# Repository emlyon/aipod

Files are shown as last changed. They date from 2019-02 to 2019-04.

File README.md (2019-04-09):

# AIpod 

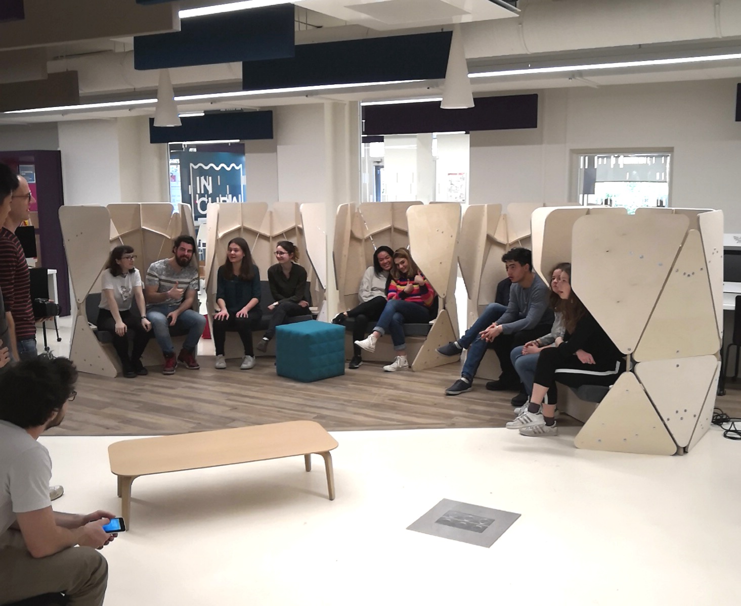
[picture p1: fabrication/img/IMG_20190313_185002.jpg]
  
AIpod is an open source chair that was designed and crafted at emlyon Business School’s makers’ lab during a bootcamp about Artificial Intelligence by staff, students and alumni.

IBM Watson NLU was used to analyze the topic, emotions and semantics of academic papers. Then, Google magenta AI composed piano musics based on this analysis. The LCD screen displays the author and title of the interpreted paper.

Seating in the chair, you can listen the sound of research, and discover research papers in a new way!

___

## Fabrication

### CNC milling

AIpod has been designed to be fabricated using a CNC router with plywood 18mm.

Use a 8mm flat milling bit to cut. The [3D model](fabrication/AIpod_chair.3dm) includes the layout for CNC milling 1250x2500mm plywood panels.

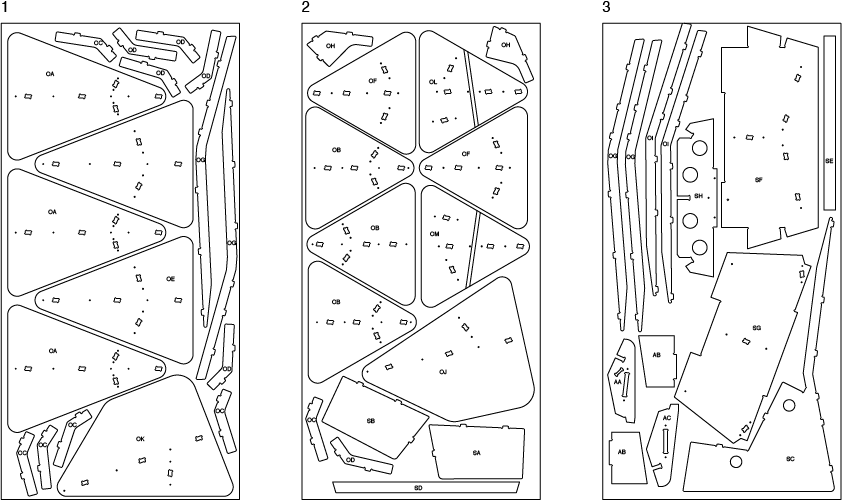
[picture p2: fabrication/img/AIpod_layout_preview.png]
AIpod_layout_preview


We used [Autodesk Fusion 360](https://www.autodesk.com/products/fusion-360/overview) to generate the toolpaths : you can find tutorials about the _Manufacture_ feature of Fusion 360 on [Autodesk website](https://f360ap.autodesk.com/courses#creating-toolpaths-and-programs-cam).

---

### Assembly

General assembly instructions can be found here : https://hackmd.io/7cDdYA7nRJGSax_ZulLNjg?both

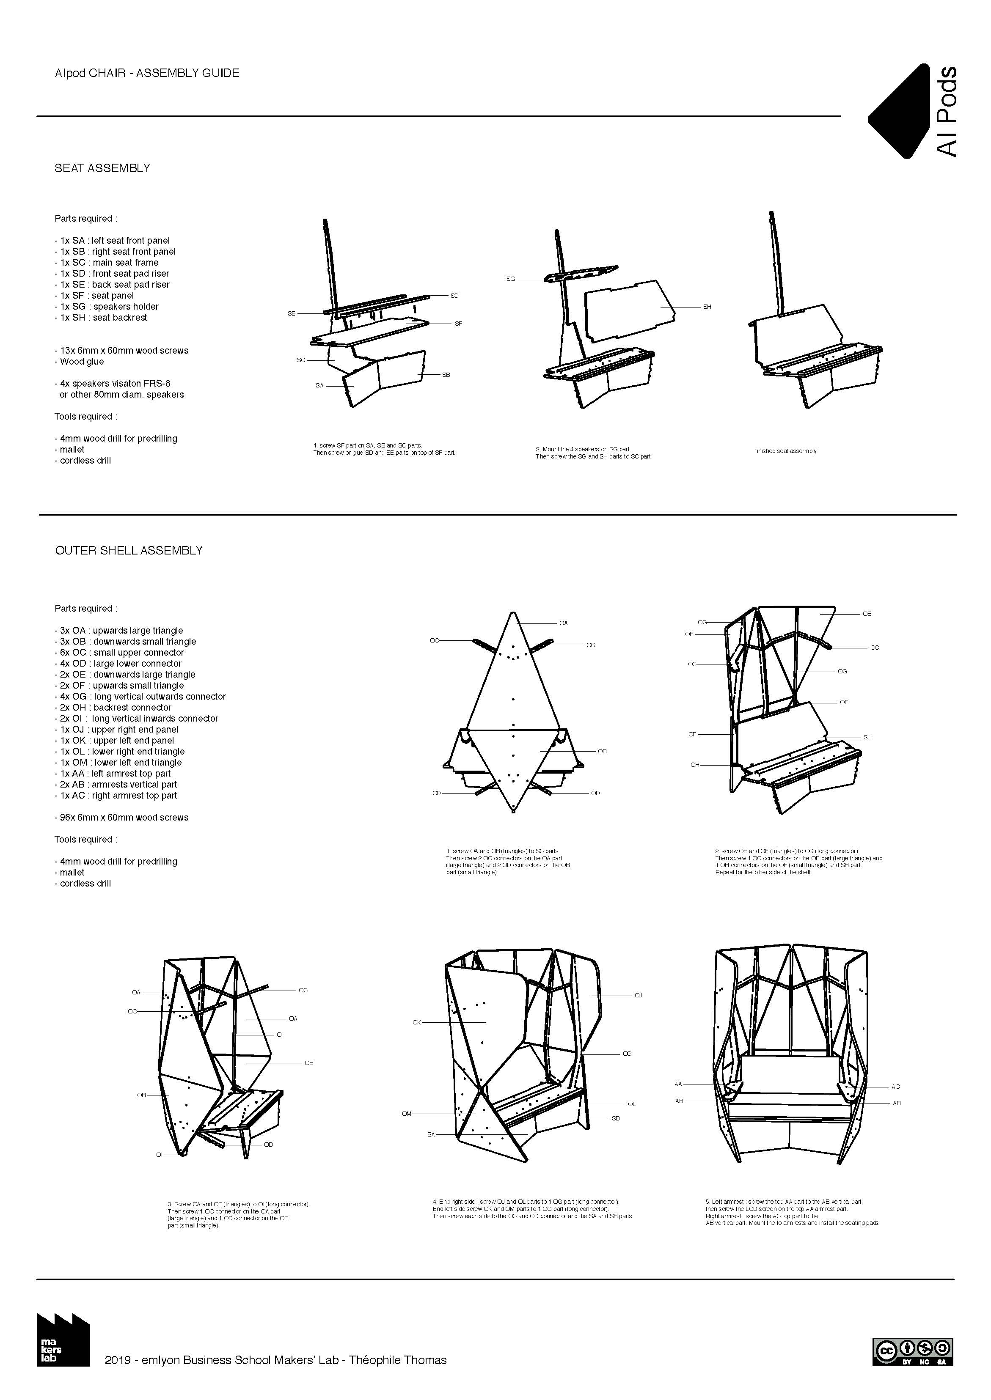
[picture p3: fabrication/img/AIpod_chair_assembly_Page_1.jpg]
  
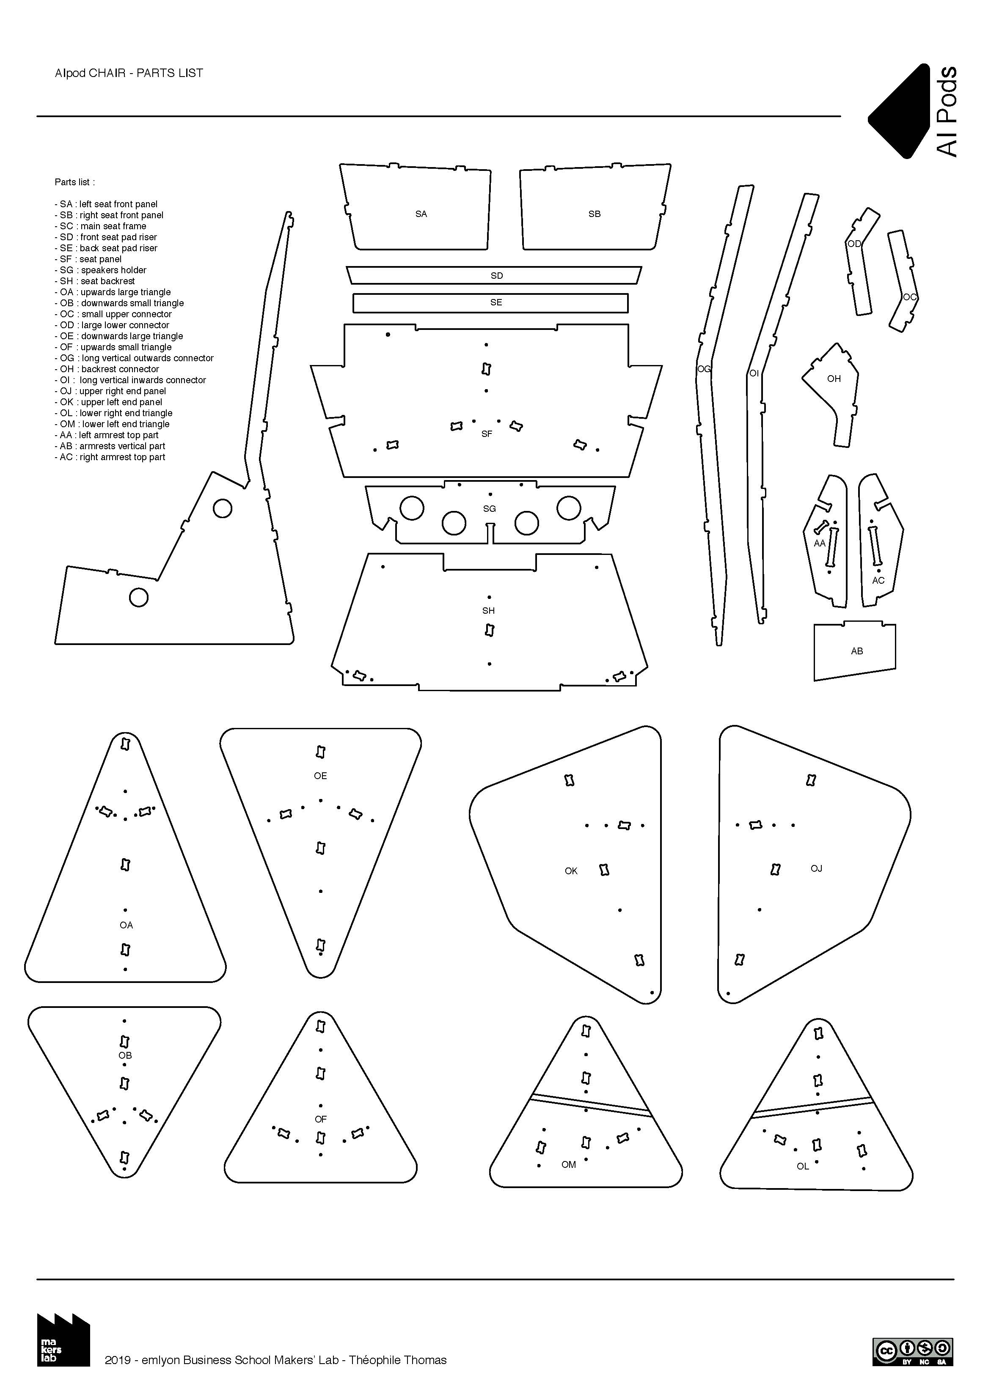
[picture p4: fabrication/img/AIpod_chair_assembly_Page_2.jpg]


A detailled list of the parts and an assembly guide can be found [in this pdf](fabrication/AIpod_chair_assembly.pdf).

___

## Electronic

### Bill of Material
- [Raspberry Pi 3](https://www.raspberrypi.org/products/)
- [16x2 LCD Display LCM1602C V2.1](http://www.datasheetcafe.com/lcm1602c-datasheet-pdf/)
- [Arcade buttons](https://www.amazon.fr/gp/product/B01N5DVINY)
- [Ampli CALIBER CA752](http://webshop.caliber.nl/products/view/details/ca75-2.html)
- [Speakers FRS 8-8 Ohm](http://www.visaton.de/en/products/fullrange-systems/frs-8-8-ohm)

### Wiring
wiring

16x2 LCD Display is connected as follow:
- RS is connected to GPIO16
- EN is connected to GPIO12
- D4 is connected to GPIO25
- D5 is connected to GPIO24
- D6 is connected to GPIO23
- D7 is connected to GPIO18
- (+ 4xGND and 2x5V)

[Buttons](https://www.amazon.fr/gp/product/B01N5DVINY) are connected to GPIO4, configured as input pullup. (+ GND)

___

### Install & run

Download the image [here](https://mega.nz/#!J9cXBCLA!xZrNihUM6XFwxSyXiPqJTmqI85lqSSZrZGT_HBga6Kw) and burn it on an 8GB micro SD using [etcher](https://www.balena.io/etcher/) or start with a fresh install of [Raspbian Stretch with desktop and recommended software](https://www.raspberrypi.org/downloads/raspbian/)

**Clone repo**
```bash
cd /home/pi
git clone https://github.com/emlyon/aipod
```

**Install Dependencies**
```bash
sudo apt-get update -y
sudo apt-get upgrade -y
sudo apt-get install python3-pip
sudo pip3 install pygame adafruit-blinka adafruit-circuitpython-charlcd
```
From [Update Your Pi to the Latest Raspbian](https://learn.adafruit.com/drive-a-16x2-lcd-directly-with-a-raspberry-pi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)

**Run**
```bash
cd /home/pi/aipod
python3 aipod.py
```

___

### Auto-update and run on boot

**Configure WIFI**
```bash
sudo raspi-config

# Set Wifi settings:
-> 2. Network Options
-> N2 Wi-fi
SSID: makerslab
passphrase: makerslab
```

**Run task on boot**
```bash
crontab -e

# and add:
@reboot sleep 10 && cd /home/pi/aipod && echo `{ git pull && echo '{"result":"up to date"}' > /home/pi/git_status.json ; } || echo '{"result":"could not update"}' > /home/pi/git_status.json` && python3 aipod.py
```

Finally create a hotspot with your phone using `makerslab`
 for **SSID and password**, and reboot the Raspberry Pi. LCD dislay should print `up to date`
 if successful, `could not update`
 otherwise.

___

### Resources
- [Adafruit-Blinka](https://pypi.org/project/Adafruit-Blinka/)
- [Adafruit CIRCUITPYTHON_CHARLCD Library](https://circuitpython.readthedocs.io/projects/charlcd/en/latest/)
- [pygame.mixer.music](https://www.pygame.org/docs/ref/music.html)
- [Drive a 16x2 LCD with the Raspberry Pi Output Character](https://learn.adafruit.com/drive-a-16x2-lcd-directly-with-a-raspberry-pi?view=all)

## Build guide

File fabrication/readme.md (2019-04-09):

# AIpod Chair

AIpod cosy chair

AIpod is an open source chair that was designed and crafted at emlyon Business School’s makers’ lab during a bootcamp about Artificial Intelligence by staff, students and alumni.

IBM Watson NLU was used to analyze the topic, emotions and semantics of academic papers. Then, Google magenta AI composed piano musics based on this analysis. The LCD screen displays the author and title of the interpreted paper.

Seating in the chair you can listen the sound of research, and discover research papers in a new way!

More info here :[makerslab.em-lyon.com](http://makerslab.em-lyon.com/)

AIpod project is licensed under the [CC by-nc-sa 4.0](https://creativecommons.org/licenses/by-nc-sa/4.0/) creative commons license



---

## Building instructions

### Electronics

Instructions for the electronics part used to play the sounds can be found on [this github repository](https://github.com/emlyon/aipod/blob/master/README.md)

---

### CNC milling

AIpod has been designed to be fabricated using a CNC router with plywood 18mm.

Use a 8mm flat milling bit to cut. The [3D model](AIpod_chair.3dm) includes the layout for CNC milling 1250x2500mm plywood panels.

AIpod_layout_preview

We used [Autodesk Fusion 360](https://www.autodesk.com/products/fusion-360/overview) to generate the toolpaths : you can find tutorials about the _Manufacture_ feature of Fusion 360 on [Autodesk website](https://f360ap.autodesk.com/courses#creating-toolpaths-and-programs-cam).

---

### Assembly

General assembly instructions can be found here : https://hackmd.io/7cDdYA7nRJGSax_ZulLNjg?both

A detailled list of the parts and an assembly guide can be found [in this pdf](AIpod_chair_assembly.pdf).

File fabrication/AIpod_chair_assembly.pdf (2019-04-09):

### OUTER SHELL ASSEMBLY

Parts required :
- 1x SA : left seat front panel
- 1x SB : right seat front panel
- 1x SC : main seat frame
- 1x SD : front seat pad riser
- 1x SE : back seat pad riser
- 1x SF : seat panel
- 1x SG : speakers holder
- 1x SH : seat backrest
- 13x 6mm x 60mm wood screws
- Wood glue
- 4x speakers visaton FRS-8
or other 80mm diam. speakers Tools required :
- 4mm wood drill for predrilling
- mallet
- cordless drill

Parts required :
- 3x OA : upwards large triangle
- 3x OB : downwards small triangle
- 6x OC : small upper connector
- 4x OD : large lower connector
- 2x OE : downwards large triangle
- 2x OF : upwards small triangle
- 4x OG : long vertical outwards connector
- 2x OH : backrest connector
- 2x OI : long vertical inwards connector
- 1x OJ : upper right end panel
- 1x OK : upper left end panel
- 1x OL : lower right end triangle
- 1x OM : lower left end triangle
- 1x AA : left armrest top part
- 2x AB : armrests vertical part
- 1x AC : right armrest top part
- 96x 6mm x 60mm wood screws Tools required :
- 4mm wood drill for predrilling
- mallet
- cordless drill
5. Left armrest : screw the top AA part to the AB vertical part,
then screw the LCD screen on the top AA armrest part.
Right armrest : screw the AC top part to the
AB vertical part. Mount the to armrests and install the seating pads
3. Screw OA and OB (triangles) to OI (long connector). Then screw 1 OC connector on the OA part
(large triangle) and 1 OD connector on the OB
part (small triangle).
4. End right side : screw OJ and OL parts to 1 OG part (long connector).
End left side screw OK and OM parts to 1 OG part (long connector).
Then screw each side to the OC and OD connector and the SA and SB parts.

OE

1. screw OA and OB (triangles) to SC parts. Then screw 2 OC connectors on the OA part (large triangle) and 2 OD connectors on the OB part (small triangle).
2. screw OE and OF (triangles) to OG (long connector).
Then screw 1 OC connectors on the OE part (large triangle) and 1 OH connectors on the OF (small triangle) and SH part. Repeat for the other side of the shell

OB

OC OC

OD | OD

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
1. screw SF part on SA, SB and SC parts.
Then screw or glue SD and SE parts on top of SF part.

SC
SB
SA

finished seat assermbly

SG

SH

2. Mount the 4 speakers on SG part.
Then screw the SG and SH parts to SC part

### SEAT ASSEMBLY

### AIpod CHAIR - ASSEMBLY GUIDE

### 2019 - emlyon Business School Makers’ Lab - Théophile Thomas

### AIpod CHAIR - PARTS LIST

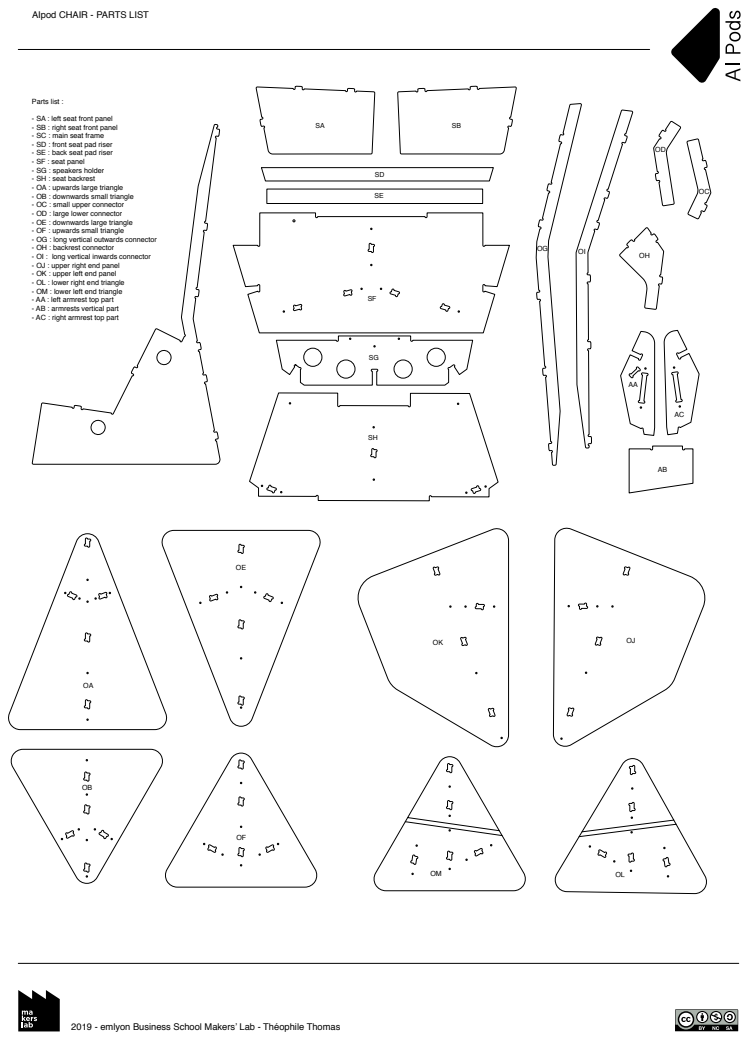
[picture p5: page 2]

Parts list :
- SA : left seat front panel
- SB : right seat front panel
- SC : main seat frame
- SD : front seat pad riser
- SE : back seat pad riser
- SF : seat panel
- SG : speakers holder
- SH : seat backrest
- OA : upwards large triangle
- OB : downwards small triangle
- OC : small upper connector
- OD : large lower connector
- OE : downwards large triangle
- OF : upwards small triangle
- OG : long vertical outwards connector
- OH : backrest connector
- OI : long vertical inwards connector
- OJ : upper right end panel
- OK : upper left end panel
- OL : lower right end triangle
- OM : lower left end triangle
- AA : left armrest top part
- AB : armrests vertical part
- AC : right armrest top part

2019 - emlyon Business School Makers’ Lab - Théophile Thomas

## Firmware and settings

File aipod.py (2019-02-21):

import json
import time
from random import randrange
import board
import digitalio
import adafruit_character_lcd.character_lcd as characterlcd
import pygame

def init_lcd():
    global digitalio, board, characterlcd, time, lcd, lcd_columns, lcd_line_1, lcd_line_2, tick_delay, last_tick, start_time

    lcd_columns = 16
    lcd_rows = 2
    lcd_rs = digitalio.DigitalInOut(board.D16)
    lcd_en = digitalio.DigitalInOut(board.D12)
    lcd_d4 = digitalio.DigitalInOut(board.D25)
    lcd_d5 = digitalio.DigitalInOut(board.D24)
    lcd_d6 = digitalio.DigitalInOut(board.D23)
    lcd_d7 = digitalio.DigitalInOut(board.D18)
    lcd = characterlcd.Character_LCD_Mono(lcd_rs, lcd_en, lcd_d4, lcd_d5, lcd_d6, lcd_d7, lcd_columns, lcd_rows)
    lcd.clear()
    lcd_line_1 = ' ' * 16
    lcd_line_2 = ' ' * 16
    tick_delay = 0.3
    last_tick = time.time()
    start_time = time.time()

def init_button():
    global digitalio, button, do_release
    button = digitalio.DigitalInOut(board.D4)
    button.direction = digitalio.Direction.INPUT
    button.pull = digitalio.Pull.UP
    button.previous_state = 'UP'
    do_release = False

def init_player():
    global pygame, music, do_fade_in, do_fade_out
    pygame.init()
    music = pygame.mixer.music
    do_fade_in = False
    do_fade_out = False

def init():
    init_lcd()
    init_button()
    init_player()

def print_git_status():
    global json, lcd, time
    with open('/home/pi/git_status.json') as git_file:
        git_status = json.load(git_file)['result']
    lcd.message = git_status
    time.sleep(5)
    lcd.clear()

def load_data():
    global data, nb_articles

    with open('output.json') as json_file:
        data = json.load(json_file)
        nb_articles = len(data)

def map_value(value, istart, istop, ostart, ostop):
    return ostart + (ostop - ostart) * ((value - istart) / (istop - istart)) if value < istop else ostop

def fade_in(start, duration):
    global music, time, do_fade_in
    v = map_value(time.time(), start, start + duration, 0, 100)/100
    music.set_volume(v)
    if v >= 1:
        do_fade_in = False

def fade_out(start, duration):
    global music, time, lcd, do_fade_out, lcd_line_1, lcd_line_2
    v = map_value(time.time(), start, start + duration, 100, 0)/100
    music.set_volume(v)
    if v <= 0:
        music.stop()
        lcd_line_1 = ' ' * 16
        lcd_line_2 = ' ' * 16
        do_fade_out = False

def play_song():
    print('play a new song')
    global nb_articles, data, lcd_line_1, lcd_line_2, music, do_fade_in, start_fade_time

    n = randrange(nb_articles)

    prefix = ' ' * 16
    lcd_line_1 = prefix + data[str(n)]['line1']
    lcd_line_2 = prefix + data[str(n)]['line2']
    lcd_line_1_len = len(lcd_line_1)
    lcd_line_2_len = len(lcd_line_2)

    # make both line the same length
    if lcd_line_1_len < lcd_line_2_len:
        lcd_line_1 = lcd_line_1 + ' ' * (lcd_line_2_len - lcd_line_1_len)
    else:
        lcd_line_2 = lcd_line_2 + ' ' * (lcd_line_1_len - lcd_line_2_len)

    music.set_volume(0)
    music.load('mp3s/' + data[str(n)]['filename'])
    music.play()

    do_fade_in = True
    start_fade_time = time.time()

init()
print_git_status()
load_data()

# Start main loop
print('Starting main loop')
while True:
    now = time.time()
    elapsed_time = now - start_time

    button.is_pressed = not button.value

    if button.is_pressed:
        do_release = False
        if button.previous_state == 'UP': # on button press
            print('button pressed')
            button.previous_state = 'DOWN'
            play_song()
            time.sleep(.5)
            start_time = time.time()
            elapsed_time = 0
    else:
        if button.previous_state == 'DOWN' and not do_release: # on button release
            print('button released')
            do_release = True
            start_release_time = now

    if do_release:
        # Check if button is still released after 4 seconds, fade out and stop music
        if now - start_release_time > 4 and not button.is_pressed:
            if button.previous_state == 'DOWN' and music.get_busy() == 1:
                print('starting fade out')
                do_fade_out = True
                start_fade_time = now
                button.previous_state = 'UP'

    if music.get_busy() == 1:
        if do_fade_out:
            fade_out(start_fade_time, 5)
        elif do_fade_in:
            fade_in(start_fade_time, 2)
    elif button.is_pressed:
        # play a new song
        play_song()
        time.sleep(.5)
        start_time = time.time()
        elapsed_time = 0

    # update lcd message
    if now - last_tick > tick_delay:
        index = int(elapsed_time / tick_delay) % len(lcd_line_1)
        line_1 = (lcd_line_1 * 2)[index:min(index + 16, len(lcd_line_1 * 2))]
        line_2 = (lcd_line_2 * 2)[index:min(index + 16, len(lcd_line_2 * 2))]
        # print(line_1 + '\n' + line_2)
        lcd.message = line_1 + '\n' + line_2
        last_tick = time.time()

    time.sleep(0.05) # small delay

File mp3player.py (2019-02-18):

# https://learn.adafruit.com/drive-a-16x2-lcd-directly-with-a-raspberry-pi?view=all
# https://www.pygame.org/docs/ref/mixer.html

import json
import time
from random import randrange
import board
import digitalio
import adafruit_character_lcd.character_lcd as characterlcd
import pygame

# Load data
with open('data.json') as json_file:
    data = json.load(json_file)

nbArticles = len(data)

# Init LCD
lcd_columns = 16
lcd_rows = 2
lcd_rs = digitalio.DigitalInOut(board.D22)
lcd_en = digitalio.DigitalInOut(board.D17)
lcd_d4 = digitalio.DigitalInOut(board.D25)
lcd_d5 = digitalio.DigitalInOut(board.D24)
lcd_d6 = digitalio.DigitalInOut(board.D23)
lcd_d7 = digitalio.DigitalInOut(board.D18)

lcd = characterlcd.Character_LCD_Mono(lcd_rs, lcd_en, lcd_d4, lcd_d5, lcd_d6, lcd_d7, lcd_columns, lcd_rows)

lcd.clear()

git_status = open('git_status.txt', 'r')
print
lcd.message = git_status
time.sleep(5)
lcd.clear()

# Init button
button = digitalio.DigitalInOut(board.D4)
button.direction = digitalio.Direction.INPUT
button.pull = digitalio.Pull.UP
button.previous_state = 'UP'
do_release = False

# Init mp3 player
pygame.init()
music = pygame.mixer.music

tick_delay = 0.3
tick = start_time = time.time()

lcd_line_1 = ' ' * 16
lcd_line_2 = ' ' * 16

def map_value(value, istart, istop, ostart, ostop):
    return ostart + (ostop - ostart) * ((value - istart) / (istop - istart))

do_fade_in = False
def fade_in(start_time, duration):
    global music, time, do_fade_in

    v = music.get_volume()
    if v < 1:
        music.set_volume(map_value(time.time(), start_time, start_time + duration, 0, 1))
    else:
        do_fade_in = False

do_fade_out = False
def fade_out(start_time, duration):
    global time, music, lcd, do_fade_out
    
    v = music.get_volume()
    if v > 0:
        music.set_volume(map_value(time.time(), start_time, start_time + duration, 1, 0))
    else:
        music.stop()
        lcd.message = (' ' * 16) + "\n" + (' ' * 16)
        do_fade_out = False

def play_song():
    global data, lcd_line_1, lcd_line_2, music, do_fade_in, start_fade_time

    n = randrange(nbArticles)

    prefix = ' ' * 16
    lcd_line_1 = prefix + data[n]['line1']
    lcd_line_2 = prefix + data[n]['line2']
    lcd_line_1_len = len(lcd_line_1)
    lcd_line_2_len = len(lcd_line_2)

    # make both line the same length
    if lcd_line_1_len < lcd_line_2_len:
        lcd_line_1 = lcd_line_1 + ' ' * (lcd_line_2_len - lcd_line_1_len)
    else:
        lcd_line_2 = lcd_line_2 + ' ' * (lcd_line_1_len - lcd_line_2_len)

    music.set_volume(0)
    music.load('mp3s/' + data[n]['mp3'])
    music.play()

    do_fade_in = True
    start_fade_time = time.time()


# Start main loop
while True:
    now = time.time()
    elapsed_time = now - start_time

    button.is_pressed = not button.value

    if button.is_pressed:
        do_release = False

        if button.previous_state == 'UP': # on button press
            button.previous_state = 'DOWN'
            play_song()

    else:
        if button.previous_state == 'DOWN': # on button release
            do_release = True
            start_release_time = now

    if do_release:
        if now - start_release_time > 4 and not button.is_pressed:
            button.previous_state = 'UP'

            if music.get_busy():
                do_fade_out = True
                start_fade_time = now

    if music.get_busy():
        if do_fade_out:
            fade_in(start_fade_time, 5)
        elif do_fade_in:
            fade_out(start_fade_time, 5)
        
        # update lcd message
        index = int(elapsed_time / tick_delay) % len(lcd_line_1)
        line_1 = (lcd_line_1 * 2)[index:min(index + 16, len(lcd_line_1 * 2))]
        line_2 = (lcd_line_2 * 2)[index:min(index + 16, len(lcd_line_2 * 2))]
        lcd.message = line_1 + '\n' + line_2 

    elif button.is_pressed:
        # play a new song
        play_song()

    time.sleep(0.01) # small delay

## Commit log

2019-02-15 bug hunt 🐞
2019-02-18 git pull on reboot + display status on screen
    [mp3player.py]
2019-02-19 add debug + fix start_time & elapsed_time
    [aipod.py]
2019-02-19 more debug: 🐞🐞🐞 hunting
2019-02-19 prevent release event to repeat
    [aipod.py]
2019-02-19 add delay after starting song to prevent infinite loop ⭕
    [aipod.py]
2019-02-19 more bug hunt 🐞
    [aipod.py]
2019-02-19 hunting bugs 🐞🐞🐞
2019-02-19 🦖🦖🦖 LCD
2019-02-19 LCD debug 🐞🐞🐞
2019-02-20 add wiring instructions + fritzing file
    [aipod.fzz]
2019-02-21 update wiring
    [aipod.fzz]
2019-02-22 update wiring + add BOM to readme
    [aipod.fzz]
2019-02-22 BOM updated
2019-03-12 Generator Code
    [input.csv]

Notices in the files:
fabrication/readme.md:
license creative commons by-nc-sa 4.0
